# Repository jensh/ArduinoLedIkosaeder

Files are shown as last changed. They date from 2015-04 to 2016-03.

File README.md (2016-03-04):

# LED Icosahedron
Icosahedron LED Icosahedron

This is the Arduino sketch for my first LED Icosahedron.
The LED part is explained on my [homepage](http://www.4k2.de/ikosaeder).

The sources are hosted on
https://github.com/jensh/ArduinoLedIkosaeder/ .

Variants of the icosahedron are in the other branches:
 * [icosaeder with smd LEDs](https://github.com/jensh/ArduinoLedIkosaeder/tree/ikosaeder2)

# Schematic
Connect the 7 LED wires (via 220Ω) with the output pins D8, D9, D2, D3, D4 and D5.
Pin D7 is unused in this sketch.

Using the auto-off powercontrol with DC-DC converter is optional:
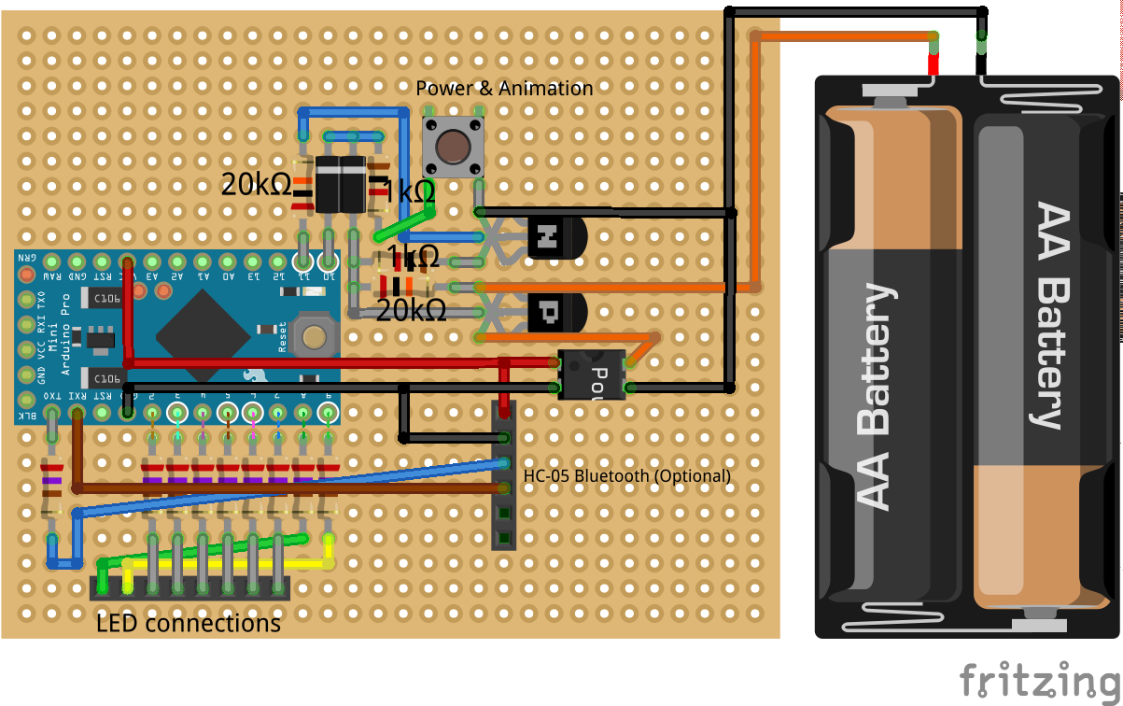
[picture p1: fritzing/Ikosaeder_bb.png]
PCB

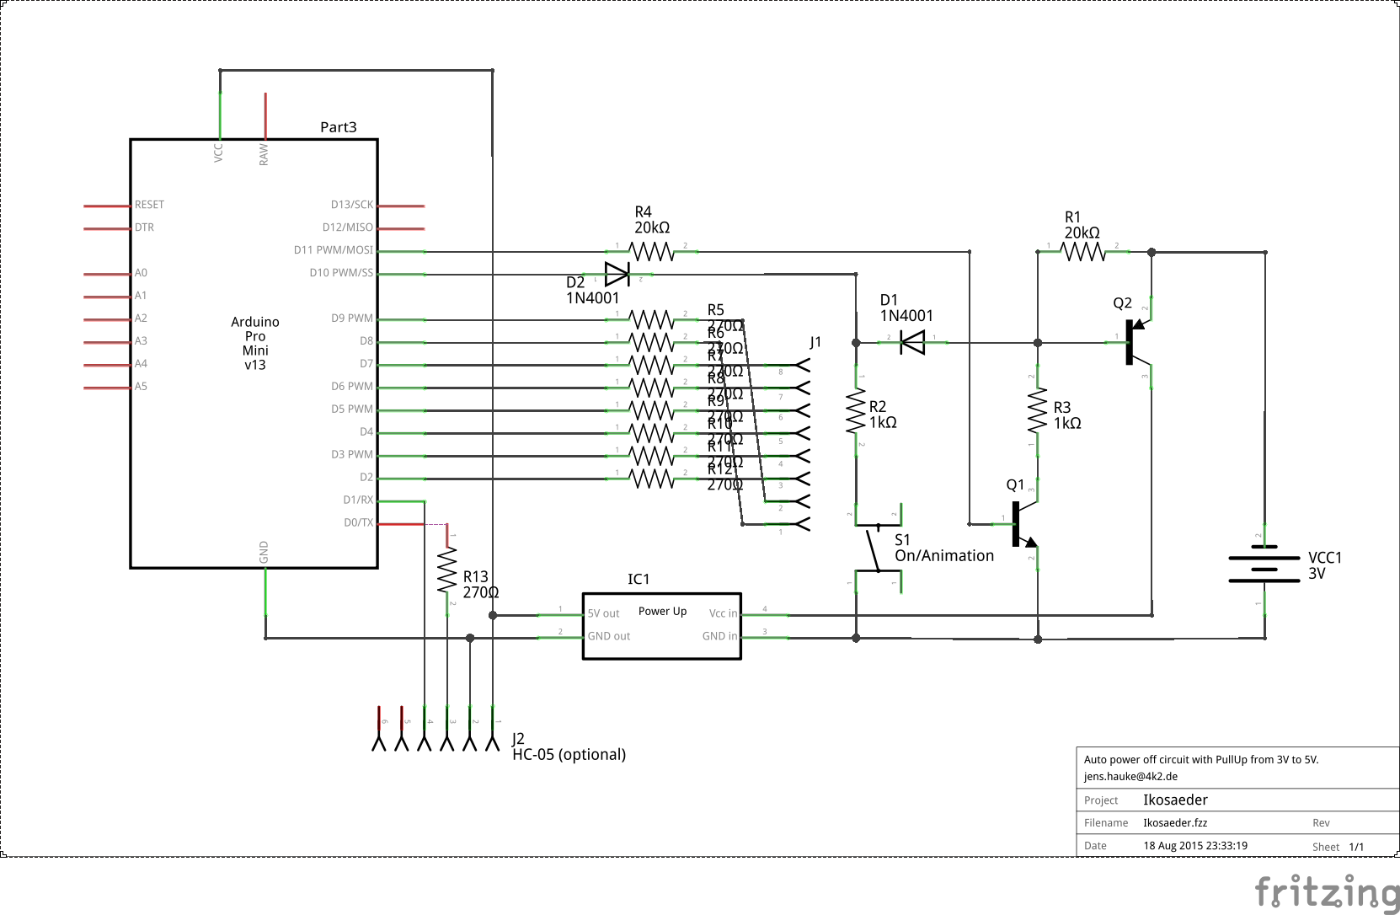
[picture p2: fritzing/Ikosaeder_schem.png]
Schematic


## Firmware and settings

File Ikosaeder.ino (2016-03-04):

//					-*- c++ -*-
// (c) 2015-03-29 Jens Hauke <jens.hauke@4k2.de>
// (c) 2016-03-01 Jens Hauke <jens.hauke@4k2.de>
//
// With (D7 D6 D5 D4 D3 D2 D9 D8)
// build a lo, hi, tri-state matrix.
// (Ikosaeder uses only 7 bits: (0 D6 D5 D4 D3 D2 D9 D8)
//
// D10: Animation switcher.
//      Input, pull up switch. Connect to GND.
//      long press: stay on for 10min instead of 1min
// D11: Power output. HIGH: on, LOW: off (Auto off feature)

#ifndef HOST_TEST

#define PIN11_POWER	11 /* Out: Power switch for auto off */
#define PIN10_ANIMATION	10 /* In: Animation switch and power on */
#define AUTOOFF_DELAY_MS 60000 /* auto power off after this time */
#define AUTOOFF_DELAY_LONG_MS 600000 /* auto power off after this time */
#define ANIMATION_DURATION 15000 /* duration of an animation, if animation_autoinc is true */


void setup() {
	// Setup D2 - D9 as Input
	for (int8_t i = 2; i <= 9; i++) {
		pinMode(i, INPUT);
	}
	pinMode(PIN10_ANIMATION, INPUT_PULLUP);
	autooff_init();

	Serial.begin(115200);
	// Serial.begin(9600);
	help();

	wait_pin10_animation_release();
}

/*
 * Auto off
 */
static
unsigned long autooff_at_ms = 0;
unsigned long autooff_delay_ms = AUTOOFF_DELAY_MS;


// Keep alive ping. Stay on for further autooff_delay_ms ms.
void autooff_ping(void) {
	autooff_at_ms = millis() + autooff_delay_ms;
}


void autooff_init(void) {
	pinMode(PIN11_POWER, OUTPUT);
	digitalWrite(PIN11_POWER, HIGH);
	autooff_ping();
}


// Power off, now.
inline
void autooff_off(void) {
	digitalWrite(PIN11_POWER, LOW);
}


// Check for timeout to power off.
void autooff_check(void) {
	// Timeout to auto power off? Unsigned long calculation!
	if (autooff_at_ms - millis() >= autooff_delay_ms) {
		// Power off, but keep running
		autooff_off();
	}
}


// Set (D7 D6 D5 D4 D3 D2 D9 D8) to lo, hi or tri-state
void set_tri(uint8_t lo_hi, uint8_t in_out) {
	uint8_t portb, portd, ddrb, ddrd;
	// Keep the state of the unused pins
	ddrd = (DDRD & B00000011) | (in_out & B11111100); // 1: Output, 0: Input
	ddrb = (DDRB & B11111100) | (in_out & B00000011);
	portd = (PORTD & B00000011) | (lo_hi & B11111100); // 0: lo, 1: hi
	portb = (PORTB & B11111100) | (lo_hi & B00000011);

	// Set registers
	PORTB = portb;
	DDRB = ddrb;
	PORTD = portd;
	DDRD = ddrd;
}
#endif

void blink_hi_lo() {
	set_tri(B11110000, B11111111); // hi and lo
	delay(1000);
	set_tri(B00001111, B11111111); // lo and hi
	delay(1000);
	set_tri(B00000000, B00000000); // All tri-state
	delay(1000);
}


// Switch on @led. Using @nbits Pins.
void set_tri_led(uint8_t nbits, int led) {
	uint8_t lo_bit = led / (nbits - 1);
	uint8_t hi_bit = (led + lo_bit) % (nbits - 1);
	if (hi_bit >= lo_bit) hi_bit++;

	// bit pos to bitmask:
	lo_bit = 1 << lo_bit;
	hi_bit = 1 << hi_bit;

	// Hi: only hi_bit, Output: lo_bit and hi_bit
	set_tri(hi_bit, lo_bit | hi_bit);
}


void tri_loop(uint8_t nbits) {
	int count = nbits * (nbits - 1);
	int i;
	for (i = 0; i < count; i++) {
		set_tri_led(nbits, i);
		delay(5);
	}
}


uint8_t led_map[8] = { 255, 255, 255, 255, 255, 255, 255, 255 };
uint8_t led_pos = 0;
uint16_t led_delay = 1;

void led_map_step(void) {
	uint8_t cnt = 0;
	uint8_t lmap;
	uint8_t lopin_mask;
	while (!((lmap = led_map[led_pos]))) {
		if (cnt++ >= 8) {
			 // empty map. Switch off.
			set_tri(0, 0);
			return;
		}
		led_pos = (led_pos + 1) & 7;
	}
	lopin_mask = 1 << led_pos;
	set_tri(lmap & ~lopin_mask, lmap | lopin_mask);
	led_pos = (led_pos + 1) & 7;
	if (led_delay) delay(led_delay);
}


void led_map_set(uint8_t row, uint8_t mask) {
	led_map[row & 7] = mask; // bit @row must be set to 0!
}


void led_map_led_set2(uint8_t row, uint8_t bit, bool on = true) {
	row = row & 7;
	if (on) {
		led_map[row] |= 1 << bit;
	} else {
		led_map[row] &= ~(1 << bit);
	}
}


void led_map_led_set(uint8_t led_id, bool on = true) {
	static struct Mapping {
		unsigned row : 3;
		unsigned bit : 3;
	} mapping[42] = {
		{1, 6}, // 0  // level 2 x
		{6, 2}, // 1  // level 4 x
		{0, 1}, // 2  // level 1 x
		{1, 3}, // 3  // level 2 x
		{2, 1}, // 4  // level 3 x
		{3, 2}, // 5  // level 3 x
		{2, 5}, // 6  // level 4 x
		{2, 3}, // 7  // level 5 x
		{6, 3}, // 8  // level 2 x
		{5, 6}, // 9  // level 4 x
		{3, 0}, // 10 // level 1 x
		{3, 1}, // 11 // level 2 x
		{5, 3}, // 12 // level 3 x
		{1, 5}, // 13 // level 3 x
		{5, 4}, // 14 // level 4 x
		{3, 5}, // 15 // level 5 x
		{6, 1}, // 16 // level 2 x
		{4, 6}, // 17 // level 4 x
		{1, 0}, // 18 // level 1 x
		{5, 1}, // 19 // level 2 x
		{1, 4}, // 20 // level 3 x
		{4, 5}, // 21 // level 3 x
		{0, 4}, // 22 // level 4 x
		{4, 3}, // 23 // level 5 x
		{6, 5}, // 24 // level 2 x
		{6, 0}, // 25 // level 4 x
		{0, 5}, // 26 // level 1 x
		{5, 2}, // 27 // level 2 x
		{5, 0}, // 28 // level 3 x
		{0, 2}, // 29 // level 3 x
		{4, 0}, // 30 // level 4 x
		{0, 3}, // 31 // level 5 x
		{2, 6}, // 32 // level 2 x
		{6, 4}, // 33 // level 4 x
		{2, 0}, // 34 // level 1 x
		{1, 2}, // 35 // level 2 x
		{2, 4}, // 36 // level 3 x
		{4, 1}, // 37 // level 3 x
		{4, 2}, // 38 // level 4 x
		{3, 4}, // 39 // level 5 x
		{0, 6}, // 40 // level 0 x
		{3, 6}, // 41 // level 6 x
	};

#ifdef HOST_TEST
	cout << "Led " << (int)led_id << " mapping: " << mapping[led_id].row <<  ", " << mapping[led_id].bit << endl;
#endif
	led_map_led_set2(mapping[led_id].row, mapping[led_id].bit, on);
}


void led_map_clear(void) {
	for (int i = 0; i < 8; i++) led_map[i] = 0;
}


void led_map_fill(void) {
	for (int i = 0; i < 8; i++) led_map[i] = 0xff;
}


void led_map_dump() {
	uint8_t i;
	for (i = 0; i < 8; i++) {
		Serial.print(i); Serial.write(','); Serial.print(led_map[i]); Serial.write("m\r\n");
	}
}


/*
 * get_peer functions:
 */
uint8_t get_peer_count(uint8_t id) {
	return (id % 8 < 2) ? 5 : 6;
}

uint8_t get_peer(uint8_t id, uint8_t dir) {
	static uint8_t num3_peers_a[][6] = {
		{ 2, 3, 4, 5+32, 3+32 }, // 0
		{ 4, 5, 6, 7, 6+32 }, // 1
		{ 40, 2+8, 3, 0, 3+32, 2+32 }, // 2
		{ 2, 2+8, 0+8, 5, 4, 0 }, // 3
		{ 0, 3, 5, 1, 6+32, 5+32 }, // 4
		{ 3, 0+8, 4+8, 6, 1, 4 }, // 5
		{ 5, 4+8, 1+8, 7+8, 7, 1 }, // 6
		{ 41, 7+32, 6+32, 1, 6, 7+8 } // 7
	};

	switch (id) {
	case 40: return (2 + 32) - dir * 8;
	case 41: return 7 + dir * 8;
	default:
		uint8_t sid = id % 8; // 0..7
		uint8_t grp = (id - sid); // 0,8,16,24,32
		uint8_t res = num3_peers_a[sid][dir];
		if (res < 40) res = (res + grp) % 40;
		return res;
	}
}


uint8_t get_peer_dir(uint8_t id, uint8_t dir) {
	static uint8_t dirs[][6] = {
		{ 3, 5, 0, 1, 2 } ,
		{ 3, 4, 5, 3, 2 } ,
		{ 6 /* marker */, 5, 0, 0, 1, 1 } ,
		{ 2, 4, 4, 0, 1, 1 } ,
		{ 2, 4, 5, 0, 1, 2 } ,
		{ 3, 3, 5, 0, 1, 2 } ,
		{ 3, 4, 4, 2, 4, 2 } ,
		{ 6 /* marker */, 5, 3, 3, 4, 1 } ,
	};

	switch (id) {
	case 40:
	case 41: return 0;
	default:
		uint8_t sid = id % 8; // 0..7
		uint8_t res = dirs[sid][dir];
		if (res == 6) {
			uint8_t grpidx = id / 8; // group index 0..4
			res = (sid == 2) ? 4 - grpidx : grpidx;
		}
		return res;
	}
}


class Walker {
public:
	uint8_t cur_id;
	uint8_t cur_dir;

	Walker() {
		cur_id = 0;
		cur_dir = 0;
	}

	/* Step in direction @dir.
	 * 0: back,
	 * On 5 node edges:
	 * 1: back right
	 * 2: forward right
	 * 3: forward left
	 * 4: back left
	 * On 6 node edges:
	 * 1: back right
	 * 2: forward right
	 * 3: forward
	 * 4: forward left
	 * 5: backward left */
	void step(uint8_t dir) {
		uint8_t c_id = cur_id;
		uint8_t peer_count = get_peer_count(c_id);

		uint8_t abs_dir = (cur_dir + dir) % peer_count;

		cur_id = get_peer(c_id, abs_dir);
		cur_dir = get_peer_dir(c_id, abs_dir);
	}

	void show(bool visible = true) {
		led_map_led_set(cur_id, visible);
	}
};


unsigned swirl_speed = 40;

void swirl_step(void) {
	static unsigned long last = 0;
	unsigned long now = millis();

	if (now - last < swirl_speed) return;
	last = now;

	led_map_clear();

	static Walker walker;

	walker.step(3 - (random(7) == 0 ? 1 : 0));
	walker.show();
}


inline
void swirl2_init(void) {
	led_map_clear();
}


void swirl2_step(void) {
	static unsigned long last = 0;
	unsigned long now = millis();

	if (now - last < swirl_speed) return;
	last = now;

	static Walker walker;
	const int tail_size = 6;
	static uint8_t pos = 0;
	static uint8_t tail[tail_size] = {0};

	// clear tail
	led_map_led_set(tail[pos], false);

	// next step show
	walker.step(3 - (random(7) == 0 ? 1 : 0));
	walker.show();

	// set head of tail
	tail[pos] = walker.cur_id;

	// progress
	pos = (pos + 1) % tail_size;
}


/*
 * swinging hemisphere
 */
struct XYZ {
	int8_t x, y, z;

	int16_t operator*(const XYZ &b) {
		return  ((int16_t)x) * b.x +
			((int16_t)y) * b.y +
			((int16_t)z) * b.z;
	}

	void scale(uint8_t s) {
		x = (((int16_t)x) * s) / 256;
		y = (((int16_t)y) * s) / 256;
		z = (((int16_t)z) * s) / 256;
	}
};

static const
XYZ koordinates[42] = {
	{ 62, -100, 0}, { 100, 0, 62}, { 0, -100, 0}, { 31, -81, 50}, { 81, -50, 31}, { 50, -31, 81},
	{ 50, 31, 81}, { 81, 50, 31}, { 0, -62, 100}, { 0, 62, 100}, { -31, -81, 50}, { -50, -31, 81},
	{ 0, 0, 100}, { -50, 31, 81}, { -31, 81, 50}, { 31, 81, 50}, { -100, 0, 62}, { -62, 100, 0},
	{ -81, -50, 31}, { -100, 0, 0}, { -81, 50, 31}, { -81, 50, -31}, { -31, 81, -50}, { 0, 100, 0},
	{ -100, 0, -62}, { 0, 62, -100}, { -81, -50, -31}, { -50, -31, -81}, { -50, 31, -81}, { 0, 0, -100},
	{ 50, 31, -81}, { 31, 81, -50}, { 0, -62, -100}, { 100, 0, -62}, { -31, -81, -50}, { 31, -81, -50},
	{ 50, -31, -81}, { 81, -50, -31}, { 100, 0, 0}, { 81, 50, -31}, { -62, -100, 0}, { 62, 100, 0}};


XYZ hemisphere_vec = {
	50, 0, 0
};
float h_x = 0.0, h_y = 0.0, h_z = 0.0;

void hemisphere_walk(int8_t &pos, float &a) {
	pos = sin(a) * 65;
	if (a > 1000) a = 0; // Limit angle range
}

void hemisphere_step(void) {
	static unsigned long last = 0;
	unsigned long now = millis();

	if (now - last < swirl_speed) return;
	last = now;


	uint8_t id;

	int16_t size = hemisphere_vec * hemisphere_vec;

	for (id = 0; id < 42; id++) {
		const XYZ &koor = koordinates[id];
		int16_t sum = hemisphere_vec * koor;

		led_map_led_set(id, sum > size);
	}

	hemisphere_walk(hemisphere_vec.x, h_x);
	hemisphere_walk(hemisphere_vec.y, h_y);
	hemisphere_walk(hemisphere_vec.z, h_z);
	h_x += 0.26;
	h_y += 0.2712;
	h_z += 0.28312;
}


#define CMD_MAX_NUMBERS 3
int cmd_number[CMD_MAX_NUMBERS];
uint8_t cmd_numbers = 0;
bool cmd_number_neg = false;

#define ANIMATION_LEDMAP 0
#define ANIMATION_NONE 1

#define ANIMATION_START ANIMATION_TRILOOP
#define ANIMATION_TRILOOP 2
#define ANIMATION_SWIRL2 3
#define ANIMATION_SWIRL 4
#define ANIMATION_HEMISPHERE 5
#define ANIMATION_LAST ANIMATION_HEMISPHERE

#define ANIMATION_AUTOINC 100 /* enable autoinc, keep current animation */

unsigned animation = ANIMATION_SWIRL2;
unsigned last_animation = ~0;
unsigned num_pins = 7;
bool animation_autoinc = true;


void help(void) {
	Serial.println("\nIkosaeder controller.");

	Serial.println("? : Help");
	Serial.println("<num>a : Set animation (100=auto)");
	Serial.println("<led number>s : Switch on led");
	Serial.println("[<num>]# : number of used pins for s");
	delay(200);
	Serial.println("[<in_out mask>,]<lo_hi mask>t : Set tri-state");
	Serial.println("<row>,<mask>m : led map");
	Serial.println("<id>|{<row>,<bit>}{l|L} : led map l:on L:off");
	Serial.println("<delay>d : delay for each led map row");
	Serial.println("<delay>S : Swirl delay");
}


bool set_or_query_param(unsigned &param, char cmd) {
	if (cmd_numbers) {
		// Set
		param = cmd_number[0];
		return true;
	} else {
		// Query
		Serial.print(param); Serial.write(cmd);
		return false;
	}
}


/*
 * Animation auto increment
 */
void animation_autoinc_step(void) {
	static unsigned long last = 0;
	unsigned long now = millis();

	if (now - last < ANIMATION_DURATION) return;
	last = now;

	animation++;
}


void animation_set(unsigned aanimation) {
	animation_autoinc = (aanimation == ANIMATION_AUTOINC);
	if (!animation_autoinc) {
		animation = aanimation;
	}
}


void SerialComm(void) {
	while (Serial.available()) {
		bool number_cmd = false;
		uint8_t cmd;
		unsigned param;

		autooff_ping();

		cmd = Serial.read();

		switch (cmd) {
		case 'a': // Animation cmd_number
			param = animation;
			if (set_or_query_param(param, 'a')) {
				animation_set(param);
			}
			break;
		case 's':
			if (cmd_numbers) {
				set_tri_led(num_pins, cmd_number[0]);
			} else {
				set_tri(0, 0); // All input. (Switch off)
			}
			animation_set(ANIMATION_NONE);
			break;
		case 'c':
		case 'S': // swirl speed
			set_or_query_param(swirl_speed, 'S');
			break;
		case 't':
			set_tri(cmd_number[1], cmd_number[0]);
			animation_set(ANIMATION_NONE);
			break;
		case '#': // Num pins
			set_or_query_param(num_pins, '#');
			break;
		case 'd': // led delay for ledmap <delay>
			set_or_query_param(led_delay, 'd');
			break;
		case 'm': // set map <row>, <mask>
			if (cmd_numbers) {
				led_map_set(cmd_number[0], cmd_number[1]);
				animation_set(ANIMATION_LEDMAP);
			} else {
				// dump map
				led_map_dump();
			}
			break;
		case 'l':
		case 'L':
			switch (cmd_numbers) {
			case 1:
				// set map <id>
				led_map_led_set(cmd_number[0], cmd == 'l');
				animation_set(ANIMATION_LEDMAP);
				break;
			case 2:
				// set map <row>, <bit>
				led_map_led_set2(cmd_number[0], cmd_number[1], cmd == 'l');
				animation_set(ANIMATION_LEDMAP);
				break;
			default:
				led_map_dump();
			}
			break;
		case 'p': // debug cmd_numbers
			Serial.print(cmd_numbers); Serial.write(',');
			Serial.print(cmd_number[0]); Serial.write(',');
			Serial.print(cmd_number[1]); Serial.write(',');
			Serial.print(cmd_number[2]); Serial.write('p');
			break;
		case 'h': // Set/ query hemisphere_vec
			switch (cmd_numbers) {
			default:
			case 3: hemisphere_vec.z = cmd_number[2];
			case 2: hemisphere_vec.y = cmd_number[1];
			case 1: hemisphere_vec.x = cmd_number[0];
				break;
			case 0:
				Serial.print(hemisphere_vec.x); Serial.write(',');
				Serial.print(hemisphere_vec.y); Serial.write(',');
				Serial.print(hemisphere_vec.z); Serial.write('h');
				break;
			}
			break;
/*
 *              Numbers
 */
		case ',':
			cmd_number[cmd_numbers] = 0;
			if (cmd_numbers < CMD_MAX_NUMBERS) cmd_numbers++;
			cmd_number_neg = false;
			number_cmd = true;
			break;
		case '-':
			// Set cmd_number negative
			cmd_number_neg = true;
			number_cmd = true;
			break;
		case '0'...'9':
			// Set cmd_number
			if (!cmd_numbers) {
				cmd_number[0] = 0;
				cmd_numbers = 1;
			}
			cmd_number[cmd_numbers - 1] *= 10;
			cmd_number[cmd_numbers - 1] += cmd_number_neg ? '0' - cmd : cmd - '0';
			number_cmd = true;
			break;
/*
 *              Misc
 */
		case '?':
			help();
			break;
		case '\n': // LF (VT102: ^j)
			Serial.print("\r\n");
			break;
		case '\r': // CR (VT102: ^m or Enter)
			Serial.print("\r\n");
			break;
		default:
			Serial.println("Unknown cmd.");
			Serial.println("Expect one of '-0123456789,?admpsSt#'");
			break;
		}

		if (!number_cmd) {
			cmd_numbers = 0;
			cmd_number_neg = false;
		}
	}
}


void wait_pin10_animation_release(void) {
	unsigned cnt = 0;
	while(!digitalRead(PIN10_ANIMATION)) {
		// tri_loop: ~ 42*5ms = 210ms.
		if (cnt < 10) {
			cnt++;
			tri_loop(num_pins);
		} else {
			// after ~2.1s switch to AUTOOFF_DELAY_LONG_MS and animation_autoinc
			autooff_delay_ms = AUTOOFF_DELAY_LONG_MS;
			autooff_ping();
			animation_autoinc = true;
			led_map_fill();
			led_map_step();
		}
	}
	// poor man's debounce
	delay(100);
}


void PushButtonComm(void) {
	if (!digitalRead(PIN10_ANIMATION)) {
		autooff_ping();
		if (animation != ANIMATION_LAST || animation_autoinc) {
			animation_set(animation + 1);
		} else {
			animation_set(ANIMATION_AUTOINC);
			for (int i = 0; i < 3; i++) {
				tri_loop(num_pins);
			}
		}
		// poor man's debounce
		delay(300);
		wait_pin10_animation_release();
	}
}


void loop() {
	// Initialize new animation?
	if (last_animation != animation) {
		switch (animation) {
		case ANIMATION_SWIRL2:
			swirl2_init();
			break;
		}
	}

	// Run animation
	switch (animation) {
	case ANIMATION_LEDMAP:
		// Static led map
		led_map_step();
		break;
	case ANIMATION_NONE:
		// Nothing. Keep state.
		break;
	case ANIMATION_TRILOOP:
		tri_loop(num_pins);
		break;
	case ANIMATION_SWIRL2:
		swirl2_step();
		led_map_step();
		break;
	case ANIMATION_SWIRL:
		swirl_step();
		led_map_step();
		break;
	case ANIMATION_HEMISPHERE:
		hemisphere_step();
		led_map_step();
		break;
	default:
		Serial.print("\"Unknown animation ");
		Serial.print(animation);
		Serial.println(". Using 2 now.\"");
		// fall through
	case ANIMATION_LAST + 1:
		animation = ANIMATION_START;
		break;
	}

	last_animation = animation;

	// Process commands
	SerialComm();
	PushButtonComm();
	if (animation_autoinc) animation_autoinc_step();
	autooff_check();
}


/*
 * Local Variables:
 *  compile-command: "arduino --upload --preserve-temp-files -v Ikosaeder.ino"
 * End:
 */

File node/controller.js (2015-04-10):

#!/usr/bin/env node
//
// (c) 2015-01-10 Jens Hauke <jens.hauke@4k2.de>
// (c) 2015-03-30 Jens Hauke <jens.hauke@4k2.de>
//

var serialPort = require("serialport");

// Docu:  https://www.npmjs.com/package/serialport

//var serialDevicePath = "/dev/rfcomm2";
var serialDevicePath = "/dev/ttyUSB0";


function Parser() {
	this.cmd_number = 0;
	this.cmd_number_neg = false;
	this.values = {};
}

Parser.prototype.push = function (ch) {
	var cmd = String.fromCharCode(ch);
	switch (cmd) {
	case '-':
		this.cmd_number_neg = true;
		var number_cmd = true;
		break;
	case '0': case '1': case '2': case '3': case '4':
	case '5': case '6': case '7': case '8': case '9':
		if (this.cmd_number === undefined) this.cmd_number = 0;
		this.cmd_number = this.cmd_number * 10;
		this.cmd_number += this.cmd_number_neg ? -cmd : +cmd;
		var number_cmd = true;
		break;
	case '\r':
	case '\n':
		// console.log('\n');
		break;
	default:
		if (ch >= 0 && ch < 128) {
			if (this.cmd_number !== undefined) {
				this.values[cmd] = this.cmd_number;
				if (this['set_' + cmd]) this['set_' + cmd](this.cmd_number);
			} else {
				if (this['get_' + cmd]) this['get_' + cmd]();
			}
		}
	}
	if (!number_cmd) {
		this.cmd_number = undefined;
		this.cmd_number_neg = false;
	}
}

parser = new Parser();

function Ikosaeder(sconn, error_check) {
	this.sconn = sconn;
	this.error_check = error_check;
}

Ikosaeder.prototype.cmd_s = function (led_num) {
	 // Switch on led_num
	this.sconn.write("" + (led_num|0) + "s", this.error_check);
}

Ikosaeder.prototype.cmd_t = function (lo_hi, in_out) {
	// Set (D7 D6 D5 D4 D3 D2 D9 D8) to lo, hi or tri-state
	this.sconn.write("" + (in_out|0) + "," + (lo_hi|0) + "t", this.error_check);
}

Ikosaeder.prototype.cmd_f = function (pin_lo, pin_hi) {
	// route from pin_lo (-) to pin_hi (+)
	var lo_hi = 1 << pin_hi;
	var in_out = lo_hi | 1 << pin_lo;

	this.cmd_t(lo_hi, in_out);
}


function communicate(callback) {
	/* Open */
	var interval;
	var sconn = new serialPort.SerialPort(serialDevicePath, {
		// Baud rate:
		// 115200, 57600, 38400, 19200, 9600 (default),
		// 4800, 2400, 1800, 1200, 600, 300, 200, 150, 134, 110, 75, 50.
		// Custom rates as allowed by hardware.
		baudrate: 115200, // 9600,
		databits: 8, // 8(default), 7, 6, or 5.
		stopbits: 1, // 1(default), 2
		parity: 'none' // 'none'(default), 'even', 'mark', 'odd', 'space'
	});


	sconn.on("open", function () {
		console.log('open');

		sconn.on('data', function(data) {
			for (var i = 0; i < data.length; i++) {
				parser.push(data[i]);
			}
		});

		var ikosaeder = new Ikosaeder(sconn, error_check);

		interval = setInterval(function () {
			step(ikosaeder);
		}, INTERVAL);

		process.on("SIGINT", function () {
			console.log("Bye-bye");
			sconn.write("ss"); // Switch off
			done();
		});
	});

	sconn.on("error", function (err) {
		console.log('Serialport: Error: ' + (err ? err : 'ok'));
		done(err);
	});

	sconn.on("close", function (err) {
		console.log('Serialport: Closed: ' + (err ? err : 'ok'));
		done(err);
	});

	function error_check(err) {
		if (err) done(err);
	}

	function done(err) {
		if (interval) clearInterval(interval);
		interval = null;

		sconn.close(function (err) {});

		if (callback) callback(err);
		callback = null;
	}
}

var intervals = [];

communicate(function (err) {
	console.log('Communication done');
	intervals.forEach(function (interval) {
		clearInterval(interval);
	});
});


parser.set_Z = function () {
	// console.log(JSON.stringify(parser.values, null, '\t'));
};

var INTERVAL = 30;
var num = 0;
var sequence = [
	//	[0, 1], [1, 6], [1, 2], [2, 6], [2, 0], [0, 6] // level 0
	//	[1, 0], [3, 0], [1, 3],     [2, 1], [4, 1], [2, 4],    [0, 2], [5, 2], [0, 5], // level 1
	// [4, 0], [4, 2], [2, 5]

	[0, 6], // level 0
	[0, 1], [0, 1], [2, 0], [2, 0], [0, 5], [0, 5], [1, 0], [1, 0], [3, 0], [3, 0], // level 1
	[1, 6], [1, 2], [2, 6], [5, 2], [6, 5], [5, 1], [6, 1], [3, 1], [6, 3], [1, 3], // level 2
	[2, 1], [4, 1], [2, 4], [0, 2], [5, 0], [4, 5], [1, 4], [1, 5], [5, 3], [3, 2], // level 3
	[6, 2], [4, 2], [6, 4], [4, 0], [6, 0], [0, 4], [4, 6], [5, 4], [5, 6], [2, 5], // level 4
	[2, 3], [2, 3], [3, 4], [3, 4], [0, 3], [0, 3], [4, 3], [4, 3], [3, 5], [3, 5], // level 5
	[3, 6],  // level 6
	[2, 3], [2, 3], [3, 4], [3, 4], [0, 3], [0, 3], [4, 3], [4, 3], [3, 5], [3, 5], // level 5
	[6, 2], [4, 2], [6, 4], [4, 0], [6, 0], [0, 4], [4, 6], [5, 4], [5, 6], [2, 5], // level 4
	[2, 1], [4, 1], [2, 4], [0, 2], [5, 0], [4, 5], [1, 4], [1, 5], [5, 3], [3, 2], // level 3
	[1, 6], [1, 2], [2, 6], [5, 2], [6, 5], [5, 1], [6, 1], [3, 1], [6, 3], [1, 3], // level 2
]

function step(ikosaeder) {
	// ikosaeder.cmd_s(num);
	ikosaeder.cmd_f(sequence[num][0], sequence[num][1]);
	console.log('step', num);

	num++;
	if (num >= sequence.length) num = 0;

}

// Local Variables:
//  compile-command: "./controller.js"
// End:

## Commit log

2015-03-30 Ikosaeder: Loop through all leds.
2015-03-30 Ikosaeder: Serial control for the leds.
2015-03-30 Ikosaeder: s command add reset if number is unset.
    [Ikosaeder.ino]
2015-03-30 Ikosaeder: controller.js: Switch off leds on SIGINT
2015-04-10 Ikosaeder: implement Led Map
2015-04-14 Ikosaeder: Push button on D10 for animation++.
2015-08-16 Ikosaeder: Implement auto power off on Pin 11.
2015-08-18 Ikosaeder: Add Breadboard layout and schema (Fritzing)
    [Ikosaeder.fzz]
2015-09-23 Add Fritzing breadboard and schematic images.
    [Ikosaeder.fzz]
2016-03-01 Update for arduino 1.6.6. Loop only through animations.
    arduino 1.6.6 did not allow static functions in *.ino.
    Animations: Skip ANIMATION_NONE and ANIMATION_LEDMAP if switched by
    animation button.
    [Ikosaeder.ino]
2016-03-04 Wait for animation switch release on startup.
2016-03-04 Long press: auto-power-off in 10min instead of 1min.
2016-03-04 Long press: auto-power-off in 10min instead of 1min + animation_autoinc.
